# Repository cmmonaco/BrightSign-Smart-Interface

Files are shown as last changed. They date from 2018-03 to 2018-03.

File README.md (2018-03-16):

# BrightSign Smart Interface

The BrightSign Smart Interface (BSSI) is a system developed expand the capabilities of the [BrightSign](https://www.brightsign.biz/) digital signage controllers. A BrightSign has 8 GPIO pins used to control playback or out elements, however, the IO is limited to simple switching input making it less useful for interactive installations where complex input is used. The BSSI system is a set of boards that contain an Arduino along with support hardware specific to the interface type. This allows for the use of multiple and complex inputs and additional processing while controlling playback on the BrightSign. Current BrightSign players no longer support the connection type used in the BSSI.

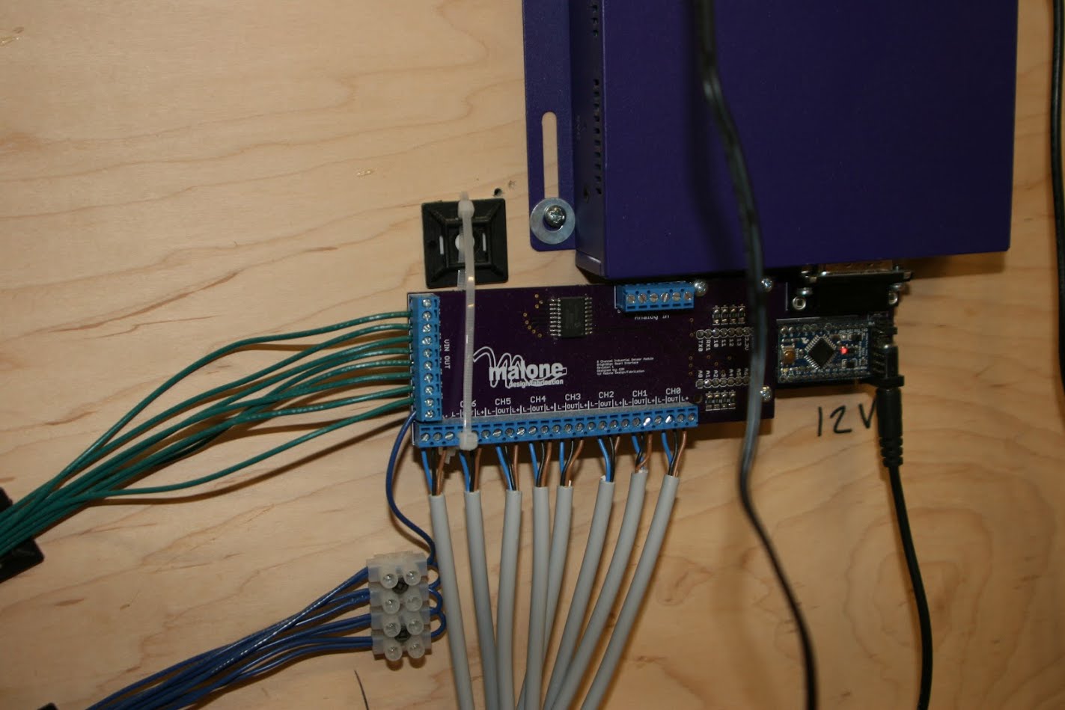
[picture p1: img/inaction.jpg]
BSSI in action


## BSSI System

The BSSI system presently consists of three boards: the main board and two expansion boards: the GPIO board, and the industrial sensor board.

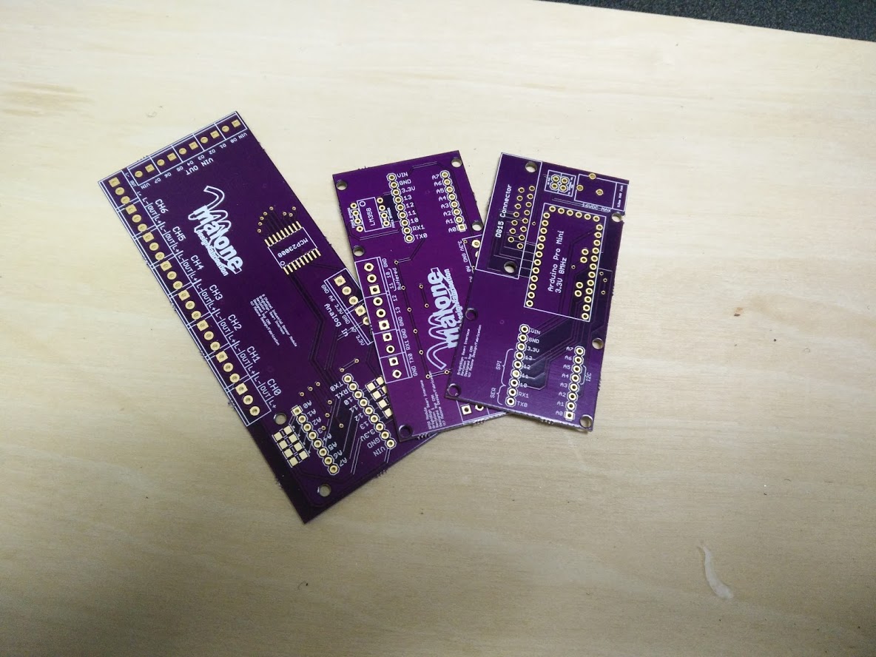
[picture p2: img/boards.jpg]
BSSI boards


### Main Board

The main board contains the Arduino and serves as the primary interface to the BrightSign. The main board also contains a power adapter, allowing the Arduino and other peripherals to be powered externally rather than by the BrightSign.

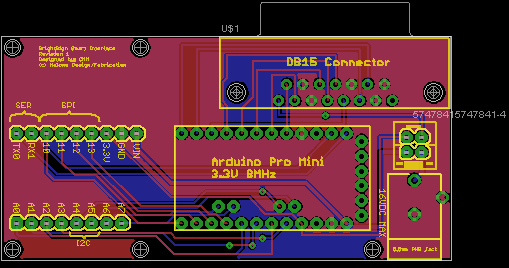
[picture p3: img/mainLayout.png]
Main board layout


### GPIO Board

The GPIO board simply break outs the remaining Arduino IO to headers. The board has locations on each pin for pull-up resistors and pins 10 and 11 are buffered (this can be bypassed).

GPIO Board

### Industrial Sensor Board

The industrial sensor board can accept up to 7 channels of NPN type industrial sensors, 8 digital GPIO, and two analog inputs. It uses a port expander IC to achieve the high number of GPIO in addition to the sensor channels. The NPN sensor are connected using the following hardware interface:

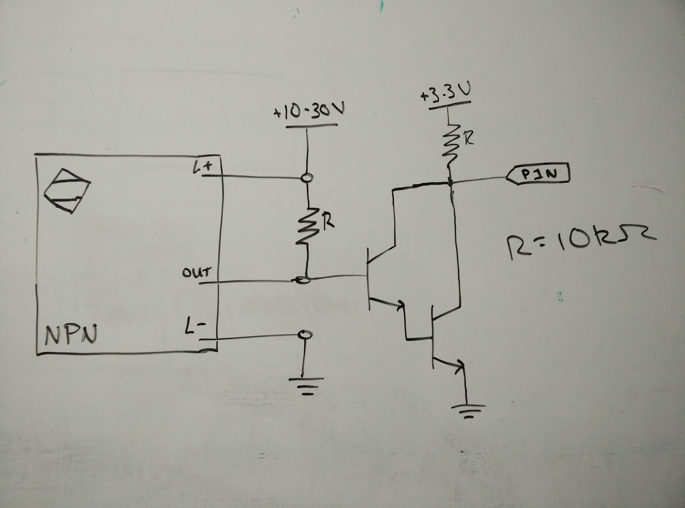
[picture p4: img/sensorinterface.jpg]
industrial sensor interface


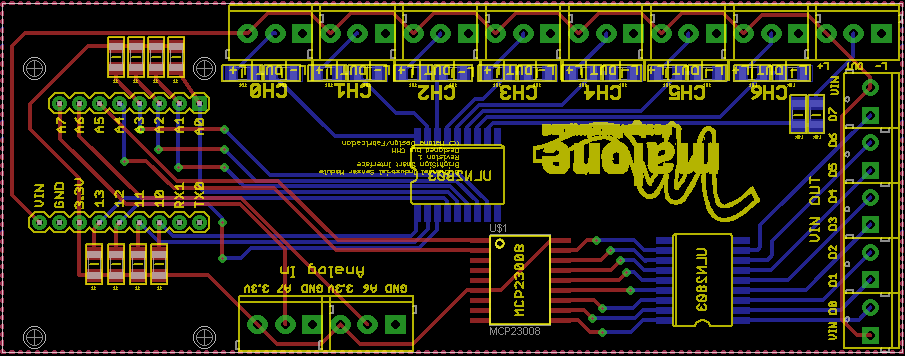
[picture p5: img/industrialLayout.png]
industrial sensor board


## BSSI Library

An Arduino library for use the the BrightSign Smart Interface is also available. See README located in library directory for details.

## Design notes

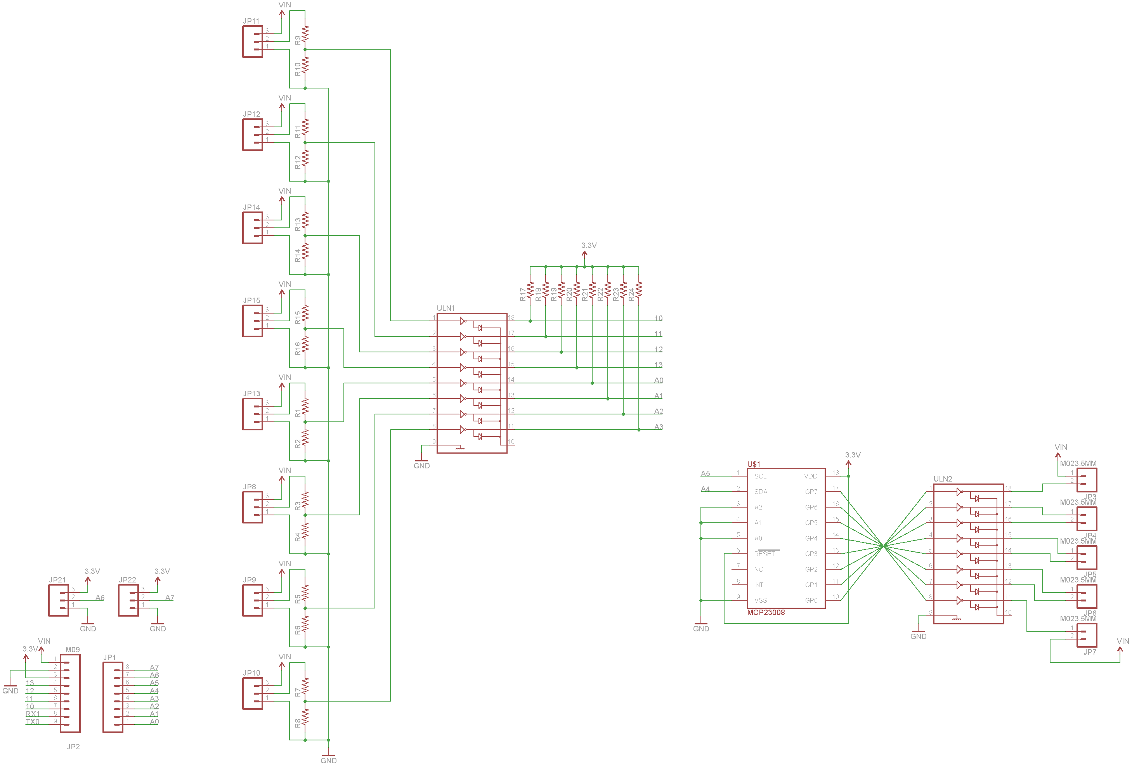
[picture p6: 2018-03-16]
img/industrialSchematic.png

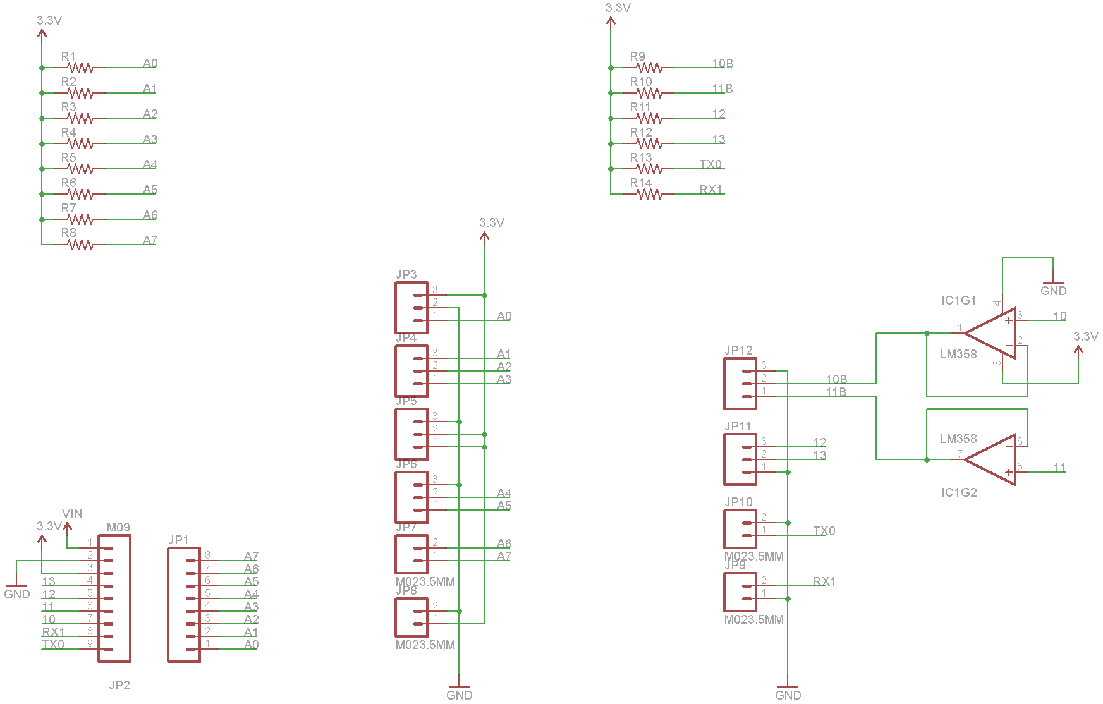
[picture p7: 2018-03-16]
img/gpioSchematic.png

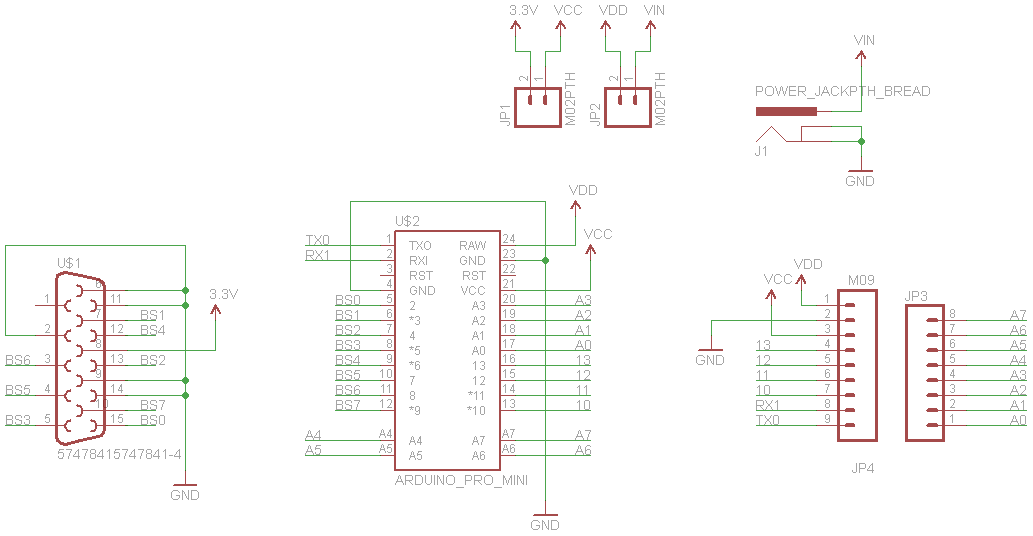
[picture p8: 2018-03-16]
img/mainSchematic.png

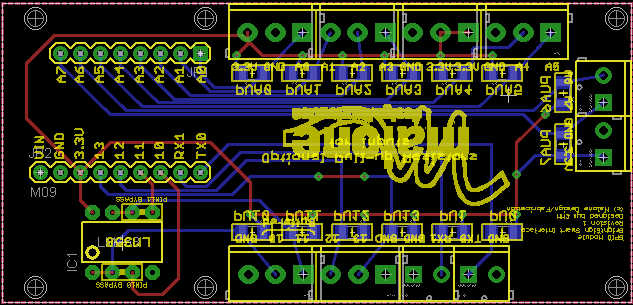
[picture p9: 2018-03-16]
img/gpioLayout.png

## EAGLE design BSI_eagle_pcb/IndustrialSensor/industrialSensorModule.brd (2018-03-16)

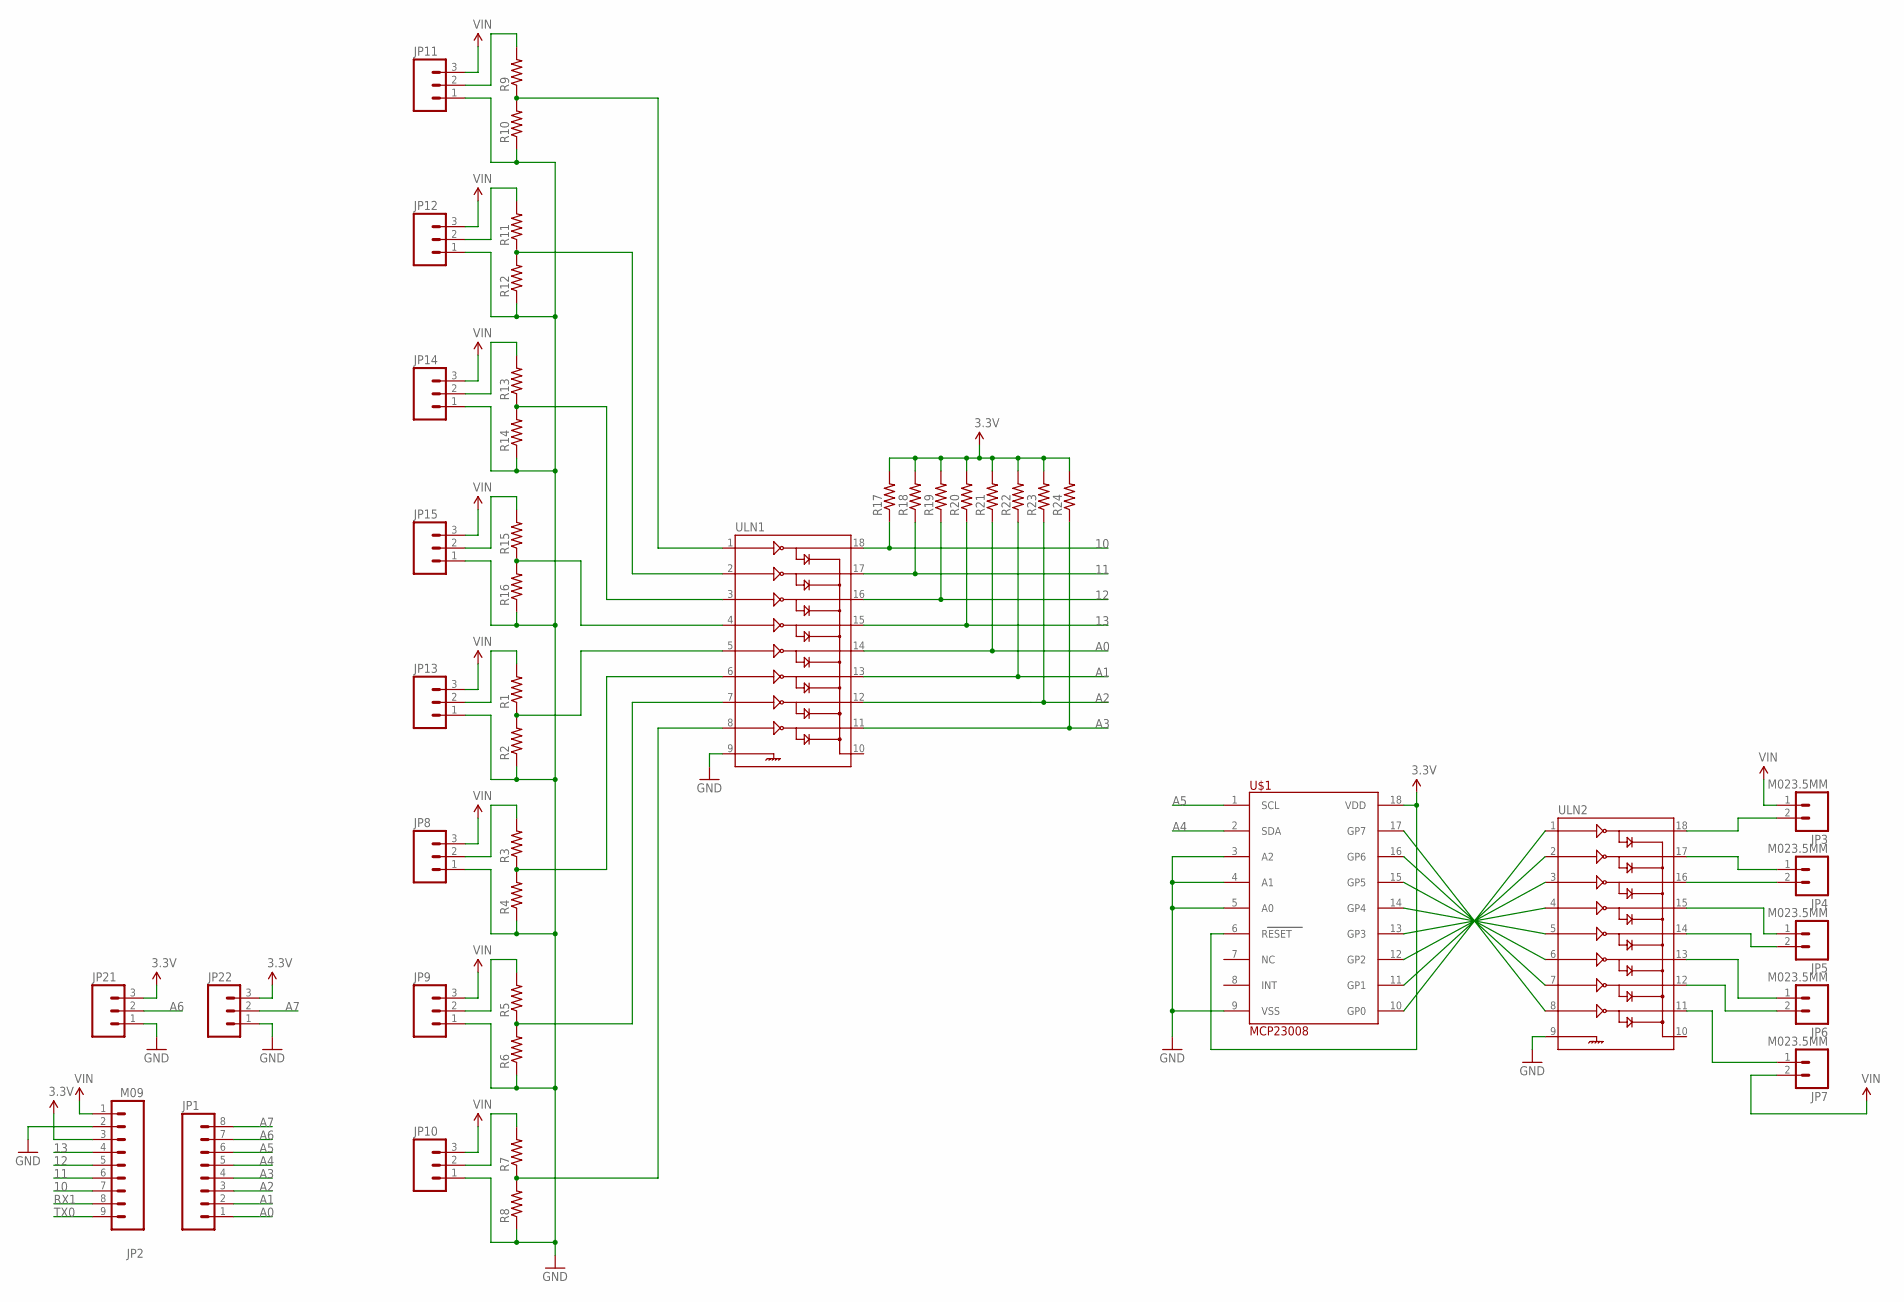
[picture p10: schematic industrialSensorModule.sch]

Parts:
JP1: M081X08; 1X08
JP2: M09; 1X09
JP3, JP4, JP5, JP6, JP7: M023.5MM; SCREWTERMINAL-3.5MM-2
JP8, JP9, JP10, JP11, JP12, JP13, JP14, JP15, JP21, JP22: M03SCREW; SCREWTERMINAL-3.5MM-3
R1, R2, R3, R4, R5, R6, R7, R8, R9, R10, R11, R12, R13, R14, R15, R16, R17, R18, R19, R20, R21, R22, R23, R24: RESISTOR1206; 1206
U$1: MCP23008; SOICW-18
ULN1, ULN2: ULN2803SOICW; SO18L

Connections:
3.3V: JP2.3, JP21.3, JP22.3, R17.2, R18.2, R19.2, R20.2, R21.2, R22.2, R23.2, R24.2, U$1.6 (RESET), U$1.18 (VDD)
10: JP2.7, R17.1, ULN1.18
11: JP2.6, R18.1, ULN1.17
12: JP2.5, R19.1, ULN1.16
13: JP2.4, R20.1, ULN1.15
A0: JP1.1, R21.1, ULN1.14
A1: JP1.2, R22.1, ULN1.13
A2: JP1.3, R23.1, ULN1.12
A3: JP1.4, R24.1, ULN1.11
A4: JP1.5, U$1.2 (SDA)
A5: JP1.6, U$1.1 (SCL)
A6: JP1.7, JP21.2
A7: JP1.8, JP22.2
GND: JP2.2, JP8.1, JP9.1, JP10.1, JP11.1, JP12.1, JP13.1, JP14.1, JP15.1, JP21.1, JP22.1, R2.1, R4.1, R6.1, R8.1, R10.1, R12.1, R14.1, R16.1, U$1.3 (A2), U$1.4 (A1), U$1.5 (A0), U$1.9 (VSS), ULN1.9, ULN2.9
unnamed: R1.1, R2.2, ULN1.5
unnamed: JP13.2, R1.2
unnamed: R3.1, R4.2, ULN1.6
unnamed: JP8.2, R3.2
unnamed: R5.1, R6.2, ULN1.7
unnamed: JP9.2, R5.2
unnamed: R7.1, R8.2, ULN1.8
unnamed: JP10.2, R7.2
unnamed: R9.1, R10.2, ULN1.1
unnamed: JP11.2, R9.2
unnamed: R11.1, R12.2, ULN1.2
unnamed: JP12.2, R11.2
unnamed: R13.1, R14.2, ULN1.3
unnamed: JP14.2, R13.2
unnamed: R15.1, R16.2, ULN1.4
unnamed: JP15.2, R15.2
unnamed: U$1.10 (GP0), ULN2.1
unnamed: U$1.11 (GP1), ULN2.2
unnamed: U$1.12 (GP2), ULN2.3
unnamed: U$1.13 (GP3), ULN2.4
unnamed: U$1.14 (GP4), ULN2.5
unnamed: U$1.15 (GP5), ULN2.6
unnamed: U$1.16 (GP6), ULN2.7
unnamed: U$1.17 (GP7), ULN2.8
unnamed: JP3.2, ULN2.18
unnamed: JP4.1, ULN2.17
unnamed: JP4.2, ULN2.16
unnamed: JP5.1, ULN2.15
unnamed: JP5.2, ULN2.14
unnamed: JP6.1, ULN2.13
unnamed: JP6.2, ULN2.12
unnamed: JP7.1, ULN2.11
RX1: JP2.8
TX0: JP2.9
VIN: JP2.1, JP3.1, JP7.2, JP8.3, JP9.3, JP10.3, JP11.3, JP12.3, JP13.3, JP14.3, JP15.3

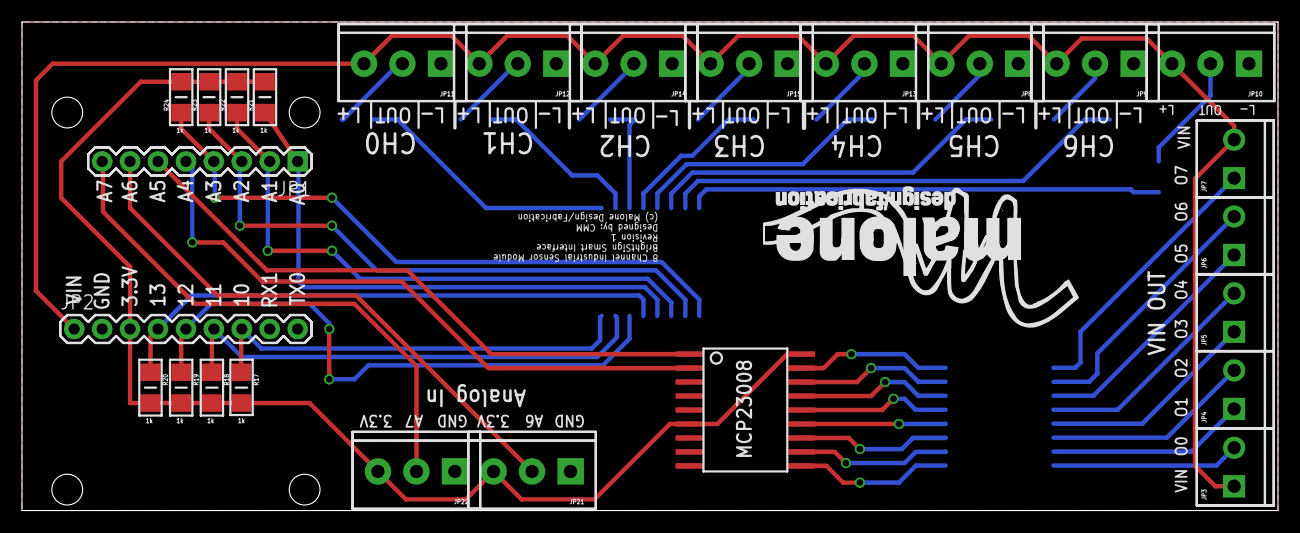
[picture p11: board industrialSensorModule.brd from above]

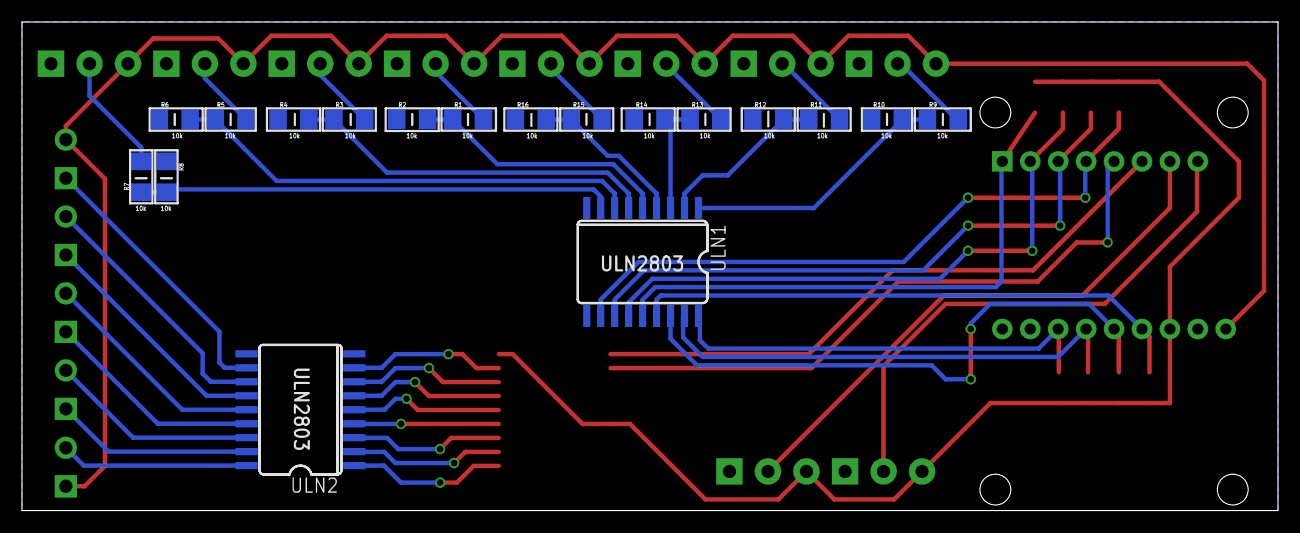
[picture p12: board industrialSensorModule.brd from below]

Board: 2 copper layers, 114.2 x 44.4 mm, 45 parts (18 on the bottom side), 47 nets.

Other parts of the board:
U$2: MALONE_LOGO

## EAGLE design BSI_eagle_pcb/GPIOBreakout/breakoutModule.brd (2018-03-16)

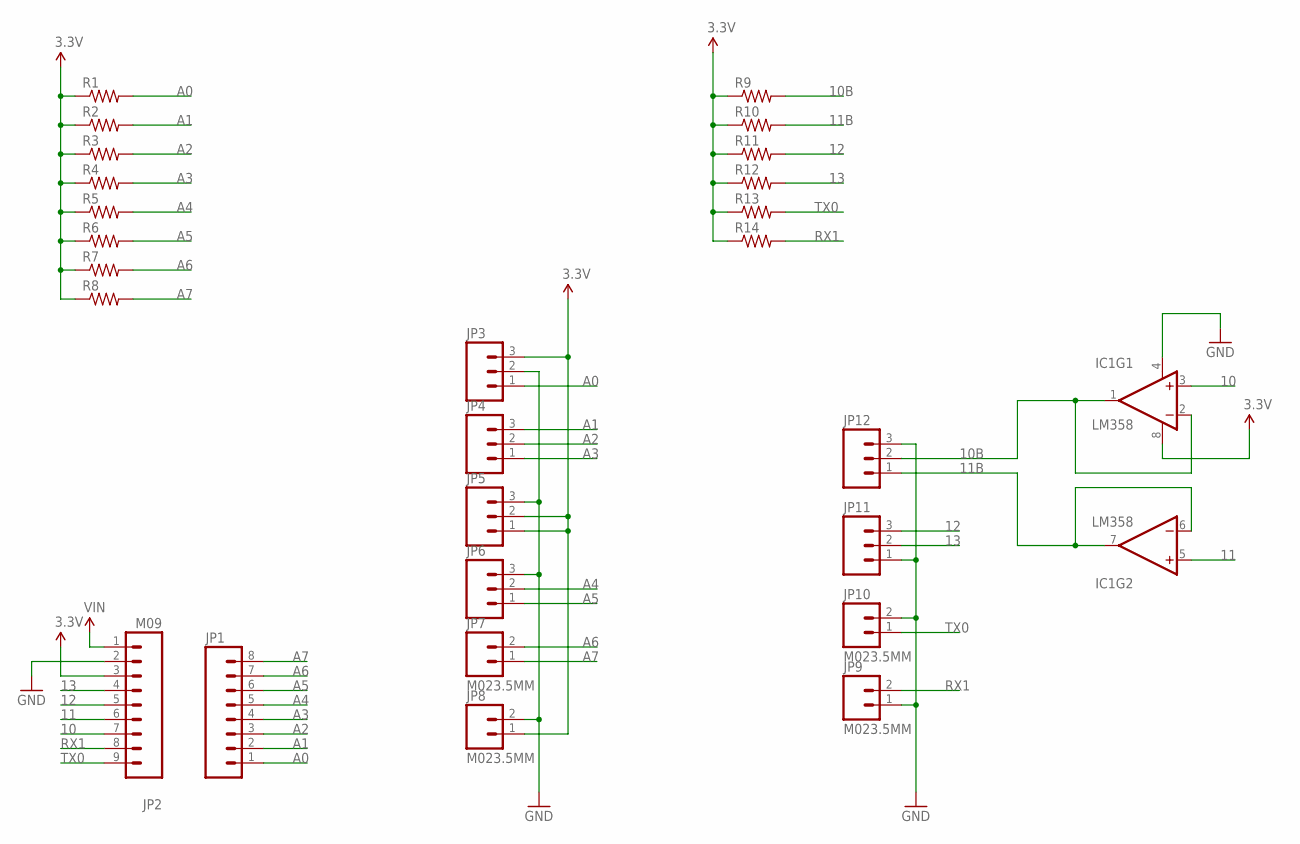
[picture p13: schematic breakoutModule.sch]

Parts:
IC1: LM358; DIP08
JP1: M081X08; 1X08
JP2: M09; 1X09
JP3, JP4, JP5, JP6, JP11, JP12: M03SCREW; SCREWTERMINAL-3.5MM-3
JP7, JP8, JP9, JP10: M023.5MM; SCREWTERMINAL-3.5MM-2
R1, R2, R3, R4, R5, R6, R7, R8, R9, R10, R11, R12, R13, R14: RESISTOR1206; 1206

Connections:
3.3V: IC1.8 (V+), JP2.3, JP3.3, JP5.1, JP5.2, JP8.1, R1.1, R2.1, R3.1, R4.1, R5.1, R6.1, R7.1, R8.1, R9.1, R10.1, R11.1, R12.1, R13.1, R14.1
10: IC1.3 (+IN), JP2.7
10B: IC1.1 (OUT), IC1.2 (-IN), JP12.2, R9.2
11: IC1.5 (+IN), JP2.6
11B: IC1.6 (-IN), IC1.7 (OUT), JP12.1, R10.2
12: JP2.5, JP11.3, R11.2
13: JP2.4, JP11.2, R12.2
A0: JP1.1, JP3.1, R1.2
A1: JP1.2, JP4.3, R2.2
A2: JP1.3, JP4.2, R3.2
A3: JP1.4, JP4.1, R4.2
A4: JP1.5, JP6.2, R5.2
A5: JP1.6, JP6.1, R6.2
A6: JP1.7, JP7.2, R7.2
A7: JP1.8, JP7.1, R8.2
GND: IC1.4 (V-), JP2.2, JP3.2, JP5.3, JP6.3, JP8.2, JP9.1, JP10.2, JP11.1, JP12.3
RX1: JP2.8, JP9.2, R14.2
TX0: JP2.9, JP10.1, R13.2
VIN: JP2.1

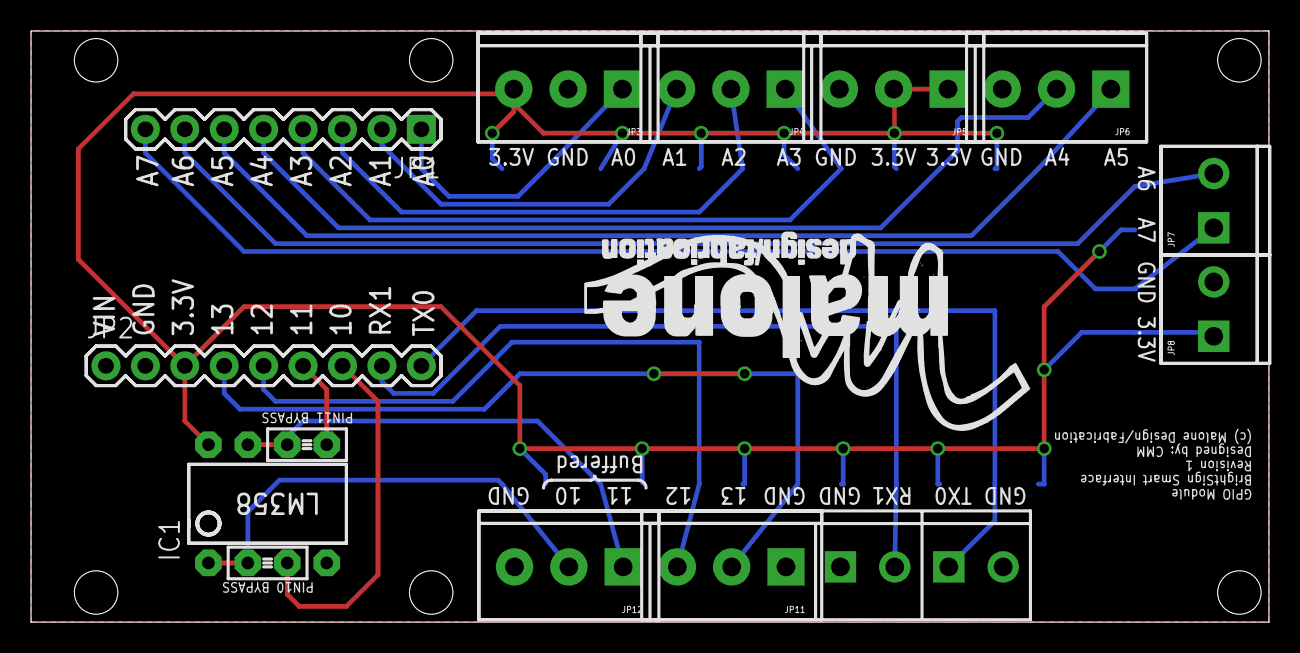
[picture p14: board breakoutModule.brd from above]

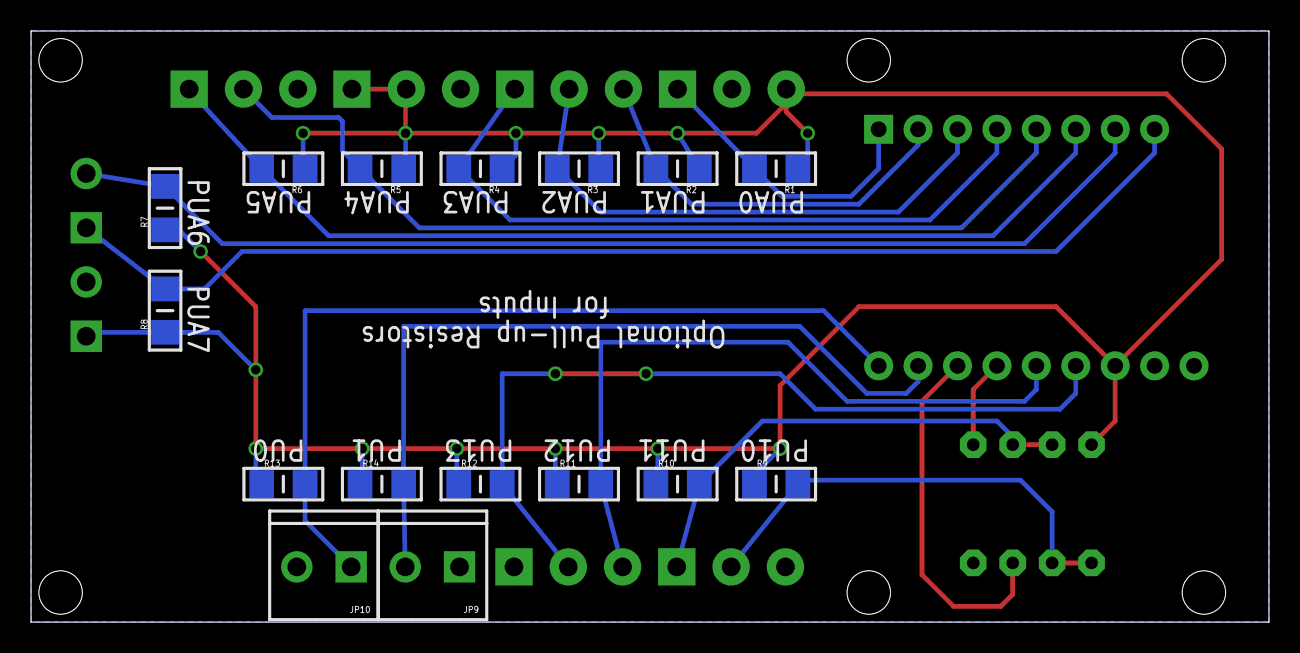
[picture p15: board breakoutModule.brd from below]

Board: 2 copper layers, 79.8 x 38.1 mm, 28 parts (16 on the bottom side), 18 nets.

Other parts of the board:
U$1: MALONE_LOGO

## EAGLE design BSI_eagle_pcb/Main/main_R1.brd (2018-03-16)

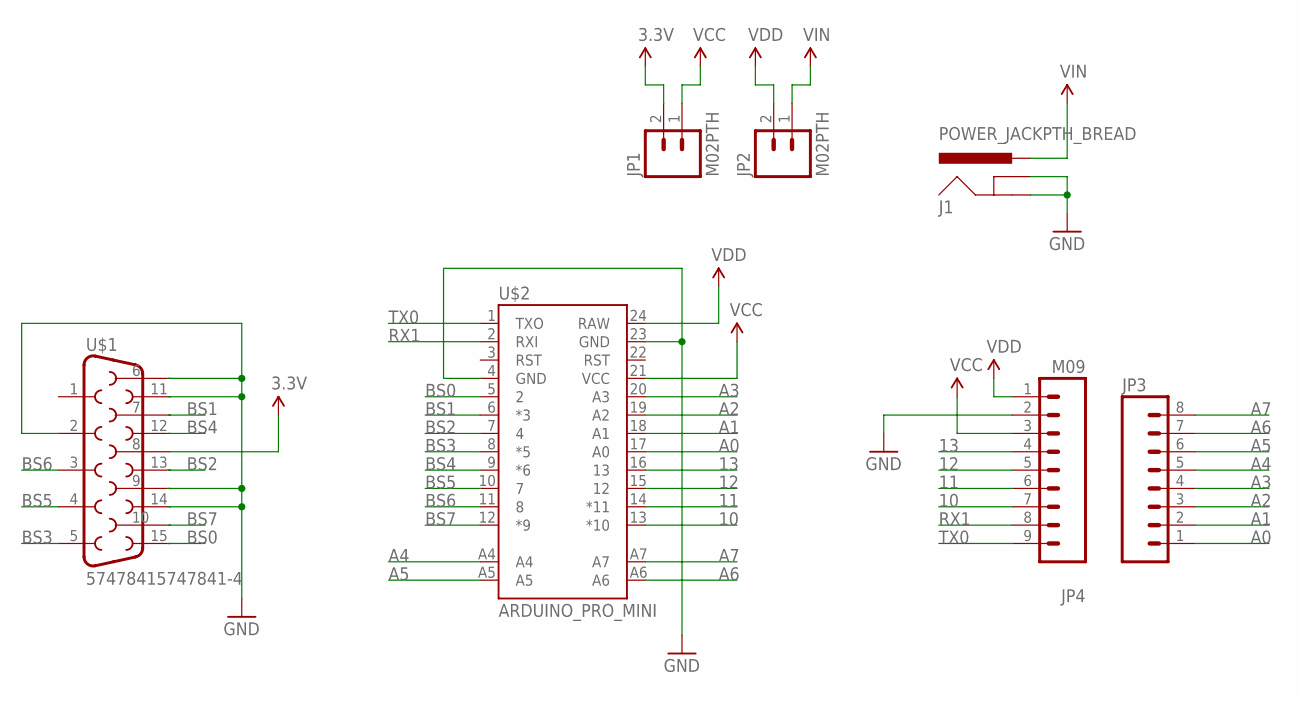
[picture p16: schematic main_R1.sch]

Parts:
J1: POWER_JACKPTH_BREAD; POWER_JACK_PTH_BREAD
JP1, JP2: M02PTH; 1X02
JP3: M081X08; 1X08
JP4: M09; 1X09
U$1: 57478415747841-4; 5747841
U$2: ARDUINO_PRO_MINI

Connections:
3.3V: JP1.2, U$1.8
10: JP4.7, U$2.13 (*10)
11: JP4.6, U$2.14 (*11)
12: JP4.5, U$2.15 (12)
13: JP4.4, U$2.16 (13)
A0: JP3.1, U$2.17 (A0)
A1: JP3.2, U$2.18 (A1)
A2: JP3.3, U$2.19 (A2)
A3: JP3.4, U$2.20 (A3)
A4: JP3.5, U$2.A4
A5: JP3.6, U$2.A5
A6: JP3.7, U$2.A6
A7: JP3.8, U$2.A7
BS0: U$1.15, U$2.5 (2)
BS1: U$1.7, U$2.6 (*3)
BS2: U$1.13, U$2.7 (4)
BS3: U$1.5, U$2.8 (*5)
BS4: U$1.12, U$2.9 (*6)
BS5: U$1.4, U$2.10 (7)
BS6: U$1.3, U$2.11 (8)
BS7: U$1.10, U$2.12 (*9)
GND: J1.GND, J1.GNDBREAK, JP4.2, U$1.2, U$1.6, U$1.9, U$1.11, U$1.14, U$2.4 (GND), U$2.23 (GND)
RX1: JP4.8, U$2.2 (RXI)
TX0: JP4.9, U$2.1 (TXO)
VCC: JP1.1, JP4.3, U$2.21 (VCC)
VDD: JP2.2, JP4.1, U$2.24 (RAW)
VIN: J1.PWR, JP2.1

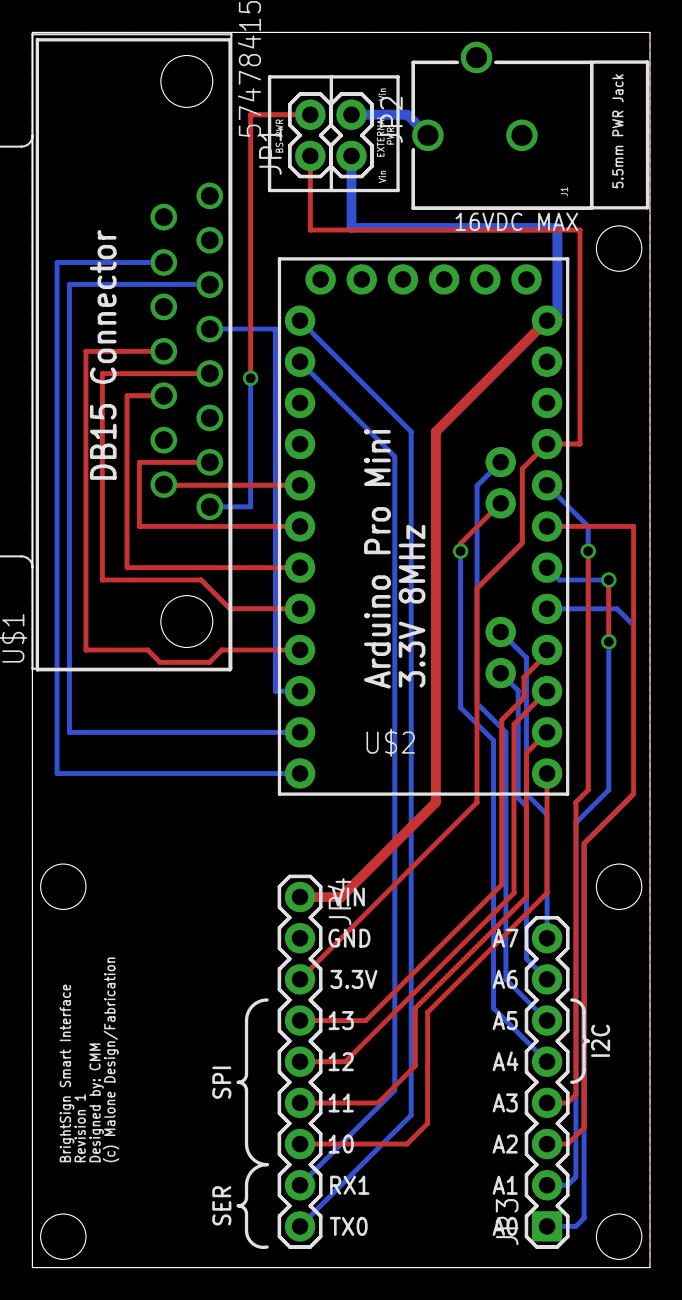
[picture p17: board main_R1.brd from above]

Board: 2 copper layers, 38.1 x 76.2 mm, 7 parts (0 on the bottom side), 27 nets.

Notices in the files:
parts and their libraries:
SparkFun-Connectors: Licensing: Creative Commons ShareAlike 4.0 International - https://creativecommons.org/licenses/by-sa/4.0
